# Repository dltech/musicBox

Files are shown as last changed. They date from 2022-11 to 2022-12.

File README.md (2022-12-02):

# musicbox
A speex codec based musical box, functions:\
*lossy sound with adoptable quality\
*cheap chipset (bios spi flash and STM32 only)\
*10 types of pre recorded songs, which can be chosen using 10 buttons\
*uploading songs through usb\
*single battery supply (using dc-dc)\
*1W power amp\
*RGB disco led

This project is not released yet, but never will be closed.\
TODO:\
*speex narrowband decoding only build (ok)\
*protocol for uploading music files through usb-com(0%)\
*pc GUI for saving songs(0%)\
*tiny pcb 15x35mm (ok)

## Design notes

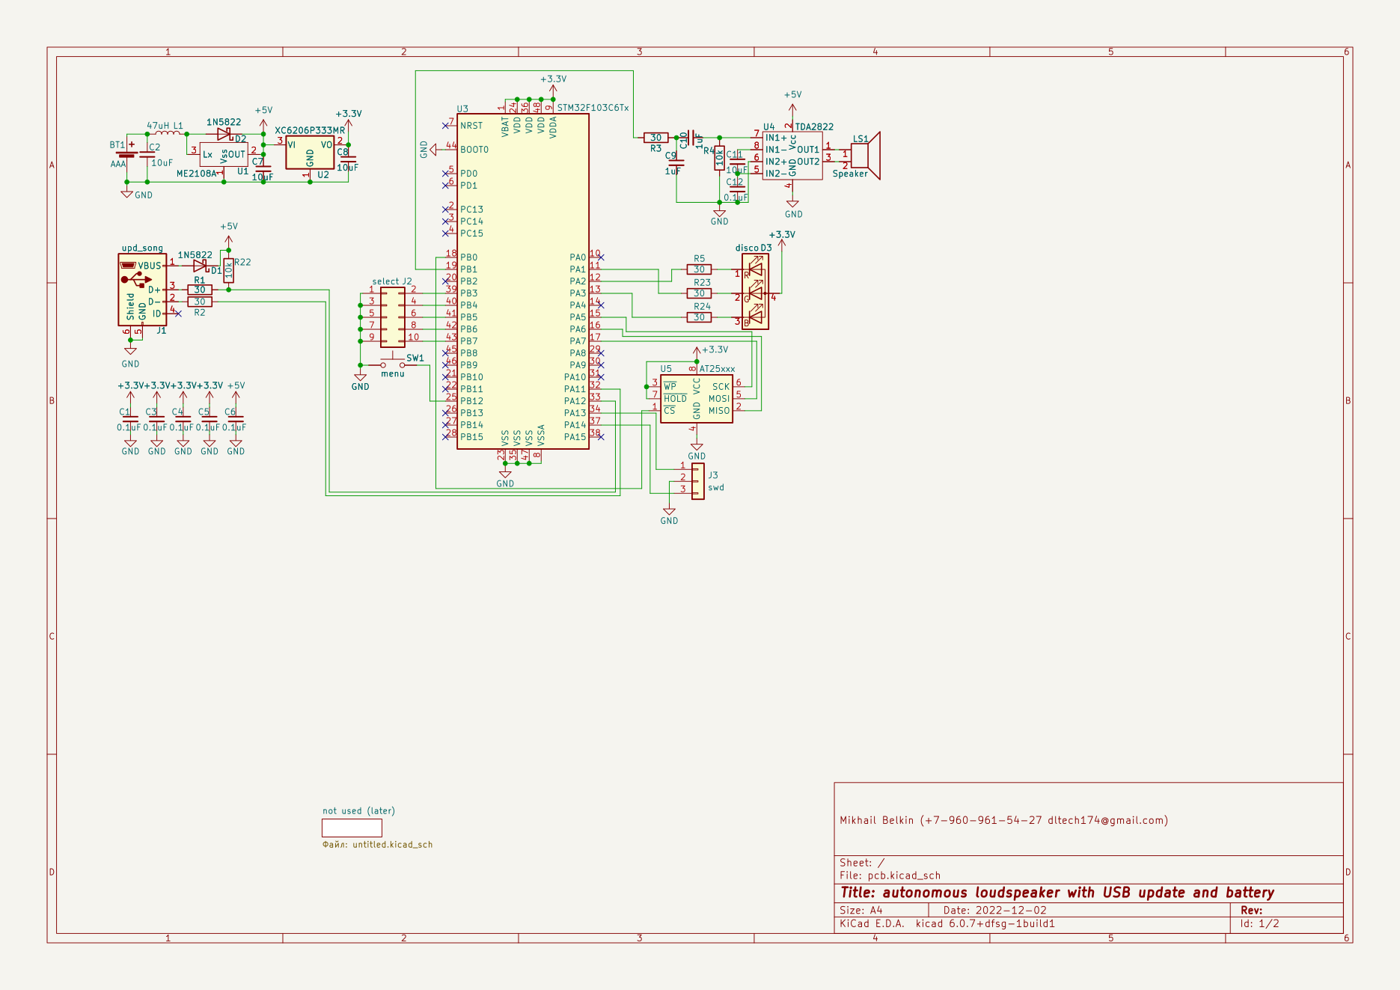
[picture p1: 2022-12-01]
pcb/pcb.png

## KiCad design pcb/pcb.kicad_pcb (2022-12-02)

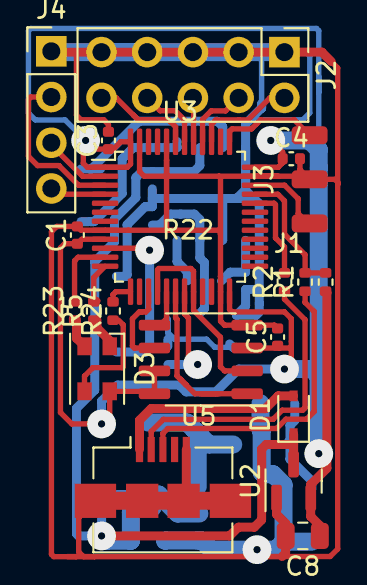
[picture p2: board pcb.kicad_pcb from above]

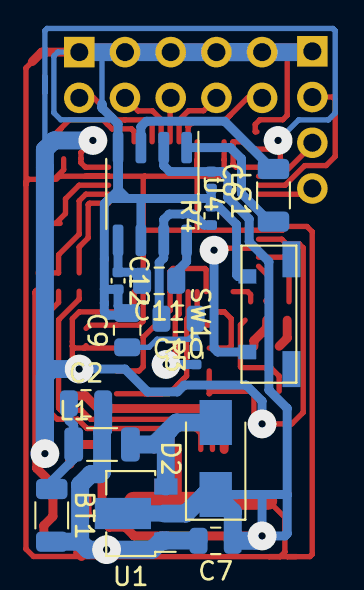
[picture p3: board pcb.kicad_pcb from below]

Board: 2 copper layers, 36 parts (16 on the bottom side), 38 nets.

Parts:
BT1: AAA; R_1206_3216Metric
C1, C3, C4, C5, C6, C12: 0.1uF; C_0402_1005Metric
C2, C7, C8, C11: 10uF; C_0805_2012Metric
C9, C10: 1uF; C_0805_2012Metric
D1: 1N5822; D_SOD-323
D2: 1N5822; D_SMA
D3: disco; LED_Cree-PLCC4_3.2x2.8mm_CCW
J1: upd_song; USB_Micro-B_Amphenol_10104110_Horizontal
J2: select; PinHeader_2x05_P2.54mm_Vertical
J3: swd; 3WIRE_PADS
J4: buttons; PinHeader_1x04_P2.54mm_Vertical
L1: 47uH; L_1206_3216Metric
LS1: Speaker; R_1206_3216Metric
R1, R2, R3, R5, R23, R24: 30; R_0402_1005Metric
R4, R22: 10k; R_0402_1005Metric
SW1: menu; smd_sw_ali
U1: ME2108A; SOT-89-3
U2: XC6206P333MR; SOT-23
U3: STM32F103C6Tx; LQFP-48_7x7mm_P0.5mm
U4: TDA2822; SO-8_3.9x4.9mm_P1.27mm
U5: AT25xxx; SO-8_3.9x4.9mm_P1.27mm

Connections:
+3.3V: C1.1, C3.1, C4.1, C5.1, C8.1, D3.4 (A), R22.1, U2.2 (VO), U3.1 (VBAT), U3.9 (VDDA), U3.24 (VDD), U3.36 (VDD), U3.48 (VDD), U5.3 (~WP), U5.7 (~HOLD), U5.8 (VCC)
+5V: C6.1, C7.1, D1.1 (K), D2.1 (K), U1.2 (OUT), U2.3 (VI), U4.2 (Vcc)
GND: BT1.2 (-), C1.2, C2.2, C3.2, C4.2, C5.2, C6.2, C7.2, C8.2, C9.2, C12.2, J1.5 (GND), J1.6 (Shield), J2.1, J2.3, J2.5, J2.7, J2.9, J3.2, J4.1, R4.2, SW1.1, U1.1 (Vss), U2.1 (GND), U3.8 (VSSA), U3.23 (VSS), U3.35 (VSS), U3.44 (BOOT0), U3.47 (VSS), U4.4 (GND), U4.6 (IN2+), U5.4 (GND)
unnamed: BT1.1 (+), C2.1, L1.1
unnamed: C9.1, C10.1, R3.2
unnamed: C10.2, R4.1, U4.7 (IN1+)
unnamed: C11.1, U4.8 (IN1-)
unnamed: C11.2, C12.1, U4.5 (IN2-)
unnamed: D1.2 (A), J1.1 (VBUS)
unnamed: D2.2 (A), L1.2, U1.3 (Lx)
unnamed: D3.1 (RK), R5.1
unnamed: D3.2 (GK), R23.1
unnamed: D3.3 (BK), R24.1
unnamed: J1.2 (D-), R2.1
unnamed: J1.3 (D+), R1.1
unnamed: J2.2, U3.39 (PB3)
unnamed: J2.4, U3.40 (PB4)
unnamed: J2.6, U3.41 (PB5)
unnamed: J2.8, U3.42 (PB6)
unnamed: J2.10, U3.43 (PB7)
unnamed: J3.1, U3.34 (PA13)
unnamed: J3.3, U3.37 (PA14)
unnamed: J4.3, U3.2 (PC13)
unnamed: J4.4, U3.4 (PC15)
unnamed: LS1.1, U4.1 (OUT1)
unnamed: LS1.2, U4.3 (OUT2)
unnamed: R2.2, U3.32 (PA11)
unnamed: R3.1, U3.19 (PB1)
unnamed: R5.2, U3.12 (PA2)
unnamed: R1.2, R22.2, U3.33 (PA12)
unnamed: R23.2, U3.11 (PA1)
unnamed: R24.2, U3.13 (PA3)
unnamed: SW1.2, U3.10 (PA0)
unnamed: J4.2, U3.3 (PC14)
unnamed: U3.15 (PA5), U5.6 (SCK)
unnamed: U3.17 (PA7), U5.5 (MOSI)
unnamed: U3.18 (PB0), U5.1 (~CS)
unnamed: U3.16 (PA6), U3.20 (PB2), U5.2 (MISO)

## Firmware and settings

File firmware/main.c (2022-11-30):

#include "inttypes.h"
#include "usbcom.h"
#include "../speex_simplified_dec/nb_celp.h"
#include "../speex_simplified_dec/modes.h"

extern const SpeexMode speex_nb_mode;
SpeexBits bits;
uint8_t music[50];
//spx_word16_t output_frame[100];
spx_word16_t output_frame[NB_FRAME_SIZE];

int main(void) {
	usbComInit();
	// speex
	speex_bits_init_buffer(&bits, music, 50);
	void *dec_state = nb_decoder_init(&speex_nb_mode);
	speex_bits_read_from(&bits, 0, 10);

	nb_decode(dec_state, &bits, output_frame);

	while(1);
}

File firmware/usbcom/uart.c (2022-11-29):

/*
 * Part of USB VCP on STM32.
 * All of UART functions including linecoding settings setup.
 *
 * Copyright 2022 Mikhail Belkin <dltech174@gmail.com>
 *
 * Licensed under the Apache License, Version 2.0 (the "License");
 * you may not use this file except in compliance with the License.
 * You may obtain a copy of the License at
 *
 *     http://www.apache.org/licenses/LICENSE-2.0
 *
 * Unless required by applicable law or agreed to in writing, software
 * distributed under the License is distributed on an "AS IS" BASIS,
 * WITHOUT WARRANTIES OR CONDITIONS OF ANY KIND, either express or implied.
 * See the License for the specific language governing permissions and
 * limitations under the License.
 */
#include "../stm32/regs/dma_regs.h"
#include "../stm32/regs/gpio_regs.h"
#include "../stm32/regs/tim_regs.h"
#include "../stm32/regs/rcc_regs.h"
#include "../stm32/regs/usart_regs.h"
#include "usb_core.h"
#include "uart.h"

volatile uint8_t uartRx[RX_SIZE];
volatile uint8_t uartTxb[TX_SIZE];
volatile int rxCnt = 0;
volatile lineCodingTyp lineCoding;

void portInit(void);
void periphInit(void);
void dmaInit(void);
void timeoutTimerInit(void);

void portInit()
{
    RCC_APB2ENR |= IOPAEN;
    GPIOA_CRH = CNF_AF_PUSH_PULL(1) | MODE_OUTPUT50(1) | CNF_FLOATING(2);
    GPIOA_ODR = 0;
}

void periphInit()
{
    RCC_APB2ENR |= USART1EN;
    USART1_CR3 |= DMAT;
    USART1_CR1 |= TE | RE | RXNEIE;
    NVIC_EnableIRQ(USART1_IRQn);
}

void dmaInit()
{
    RCC_AHBENR |= DMA1EN;
    DMA1_CPAR4  = (uint32_t)&USART1_DR;
    DMA1_CMAR4  = (uint32_t)uartTxb;
    DMA1_CNDTR4 = 1;
    DMA1_CCR4   = MINC | MSIZE_8BIT | PSIZE_8BIT | PL_LOW | DIR | TCIE;
//    NVIC_EnableIRQ(DMA1_Channel4_IRQn);
}

void timeoutTimerInit()
{
    // Timer interrupt for data Rx timeout
    RCC_APB1ENR |= TIM2EN;
    TIM2_CR1  = OPM | CKD_CK_INT;
    TIM2_PSC  = PSC_400BAUD;
    TIM2_ARR  = 0xffff;
    TIM2_DIER = UIE;
    TIM2_SR   = 0;
    TIM2_EGR |= UG;
    NVIC_EnableIRQ(TIM2_IRQn);
//    nvic_set_priority(NVIC_TIM2_IRQ, 0x00);
}

void uartInit()
{
    portInit();
    periphInit();
    lineCodingTyp initConf;
    initConf.dwDTERate = 9600;
    initConf.bCharFormat = LINE_STOP_BIT_1;
    initConf.bParityType = LINE_PARITY_NONE;
    initConf.bDataBits = 8;
    uartSetLine(&initConf);
    dmaInit();
    timeoutTimerInit();
    USART1_CR1 |= UE;
}

// install usart settings using setlinecoding parameters
void uartSetLine(lineCodingTyp *line)
{
    USART1_BRR = USART_BR_CALC(line->dwDTERate);
    if(line->bCharFormat == LINE_STOP_BIT_1P5)  USART1_CR2 = STOP_1P5;
    if(line->bCharFormat == LINE_STOP_BIT_2)    USART1_CR2 = STOP_2;
    USART1_CR1 &= ~((uint32_t)(PS | PCE | M));
    if(line->bParityType == LINE_PARITY_ODD)    USART1_CR1 |= PCE | PS;
    if(line->bParityType == LINE_PARITY_EVEN)   USART1_CR1 |= PCE;
    if(line->bDataBits == 9)                    USART1_CR1 |= M;
    TIM2_ARR = TOUT_CALC(line->dwDTERate);
    TIM2_EGR |= UG;
    TIM2_CR1 |= CEN;
    lineCoding = *line;
}

void USART1_Handler()
{
    if((USART1_SR & RXNE) > 0) {
        uartRx[rxCnt++] = (uint8_t)USART1_DR;
        if(rxCnt == RX_SIZE) {
            vcpTx((uint8_t*)uartRx,rxCnt);
            rxCnt = 0;
        }
        TIM2_CNT = 0;
    }
    USART1_SR = 0;
}

void TIM2_Handler()
{
    TIM2_SR = 0;
    if( rxCnt > 0 ) {
        vcpTx((uint8_t*)uartRx,rxCnt);
        rxCnt = 0;
    }
    TIM2_CNT = 0;
    TIM2_CR1 |= CEN;
}

void uartTx(uint8_t *data, int size)
{
    DMA1_CCR4 &= ~((uint32_t)DMA_EN);
    for(int i=0 ; i<size ; ++i) uartTxb[i] = data[i];
    DMA1_CNDTR4 = (uint32_t)size;
    DMA1_CCR4 |= DMA_EN;
}

void DMA1_Channel4_Handler()
{
//    DMA1_CCR4 &= ~((uint32_t)DMA_EN);
}

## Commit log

2022-11-29 filters.c almost compiled
2022-12-01 pcb almost compl
    [pcb.kicad_pcb, pcb.kicad_sch, untitled.kicad_sch]
2022-12-02 pcb ok
    [pcb.kicad_pcb, pcb.kicad_sch]
